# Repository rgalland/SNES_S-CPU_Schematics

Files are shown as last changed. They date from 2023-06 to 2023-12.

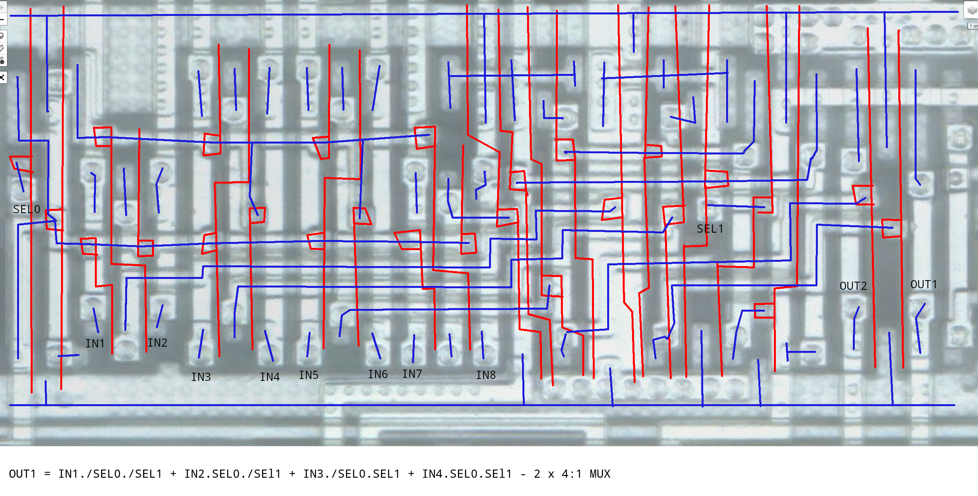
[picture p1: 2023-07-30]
S-CPU_gates/MUX_2x4:1.png

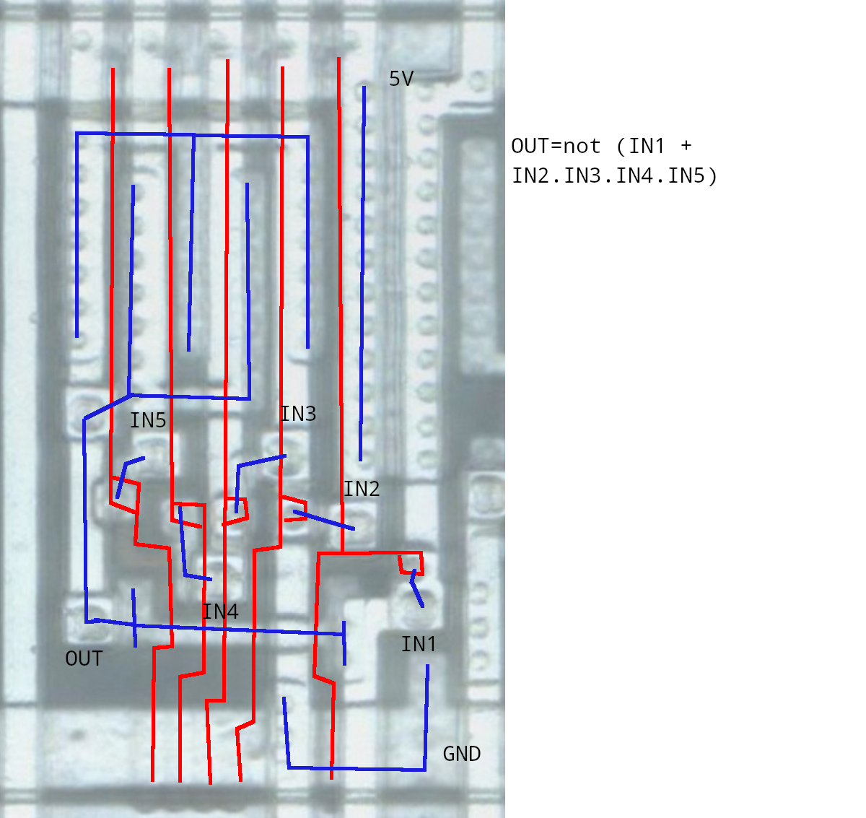
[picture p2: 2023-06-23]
S-CPU_gates/AOI_14.png

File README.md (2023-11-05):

# SNES_S-CPU_Schematics
Reverse engineering of the SNES CPU from die shots found at https://siliconpr0n.org/map/nintendo/s-cpu-a/single/nintendo_s-cpu-a_mcmaster_mz_ns20x.jpg
SVG file has link to die shot but is not included in repository because of its large size. Download it from link above and copy into the root of this repository. 
Inkscape has been used to create and edit the SVG file.

- All cell types have been identified (with the exception of the 65816 section)
- All cells have been allocated a 4 letter unique identifier in the SVG file
- All cells captured are in Kicad schematics
- Schematics rearranged in sections. Only some DMA section still require a few more notes and to be tidied up.
- TODO: Adding 65816 as a component (still some unknow external connections .. to me anyway)

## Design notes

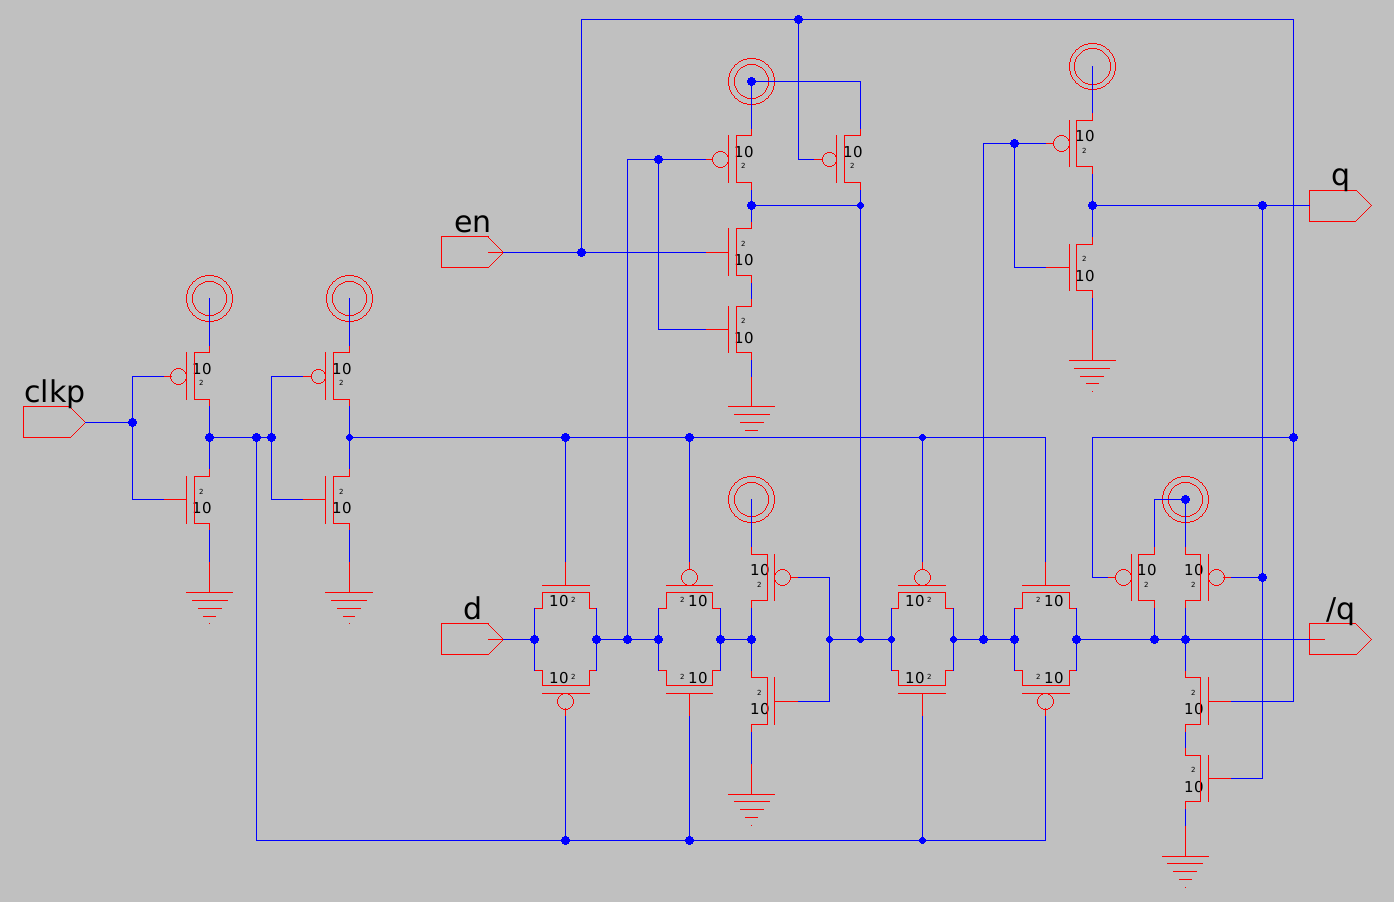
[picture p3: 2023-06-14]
S-CPU_vlsi/dff_wEN_CLKInv.png

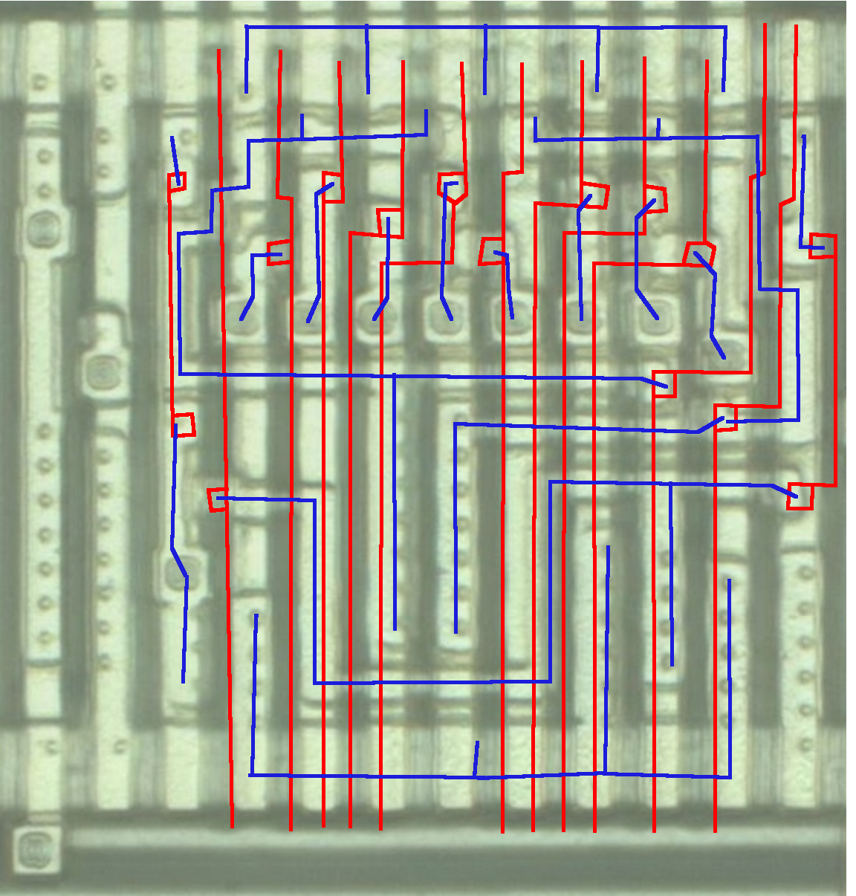
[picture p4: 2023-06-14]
S-CPU_gates/NOR_8.png

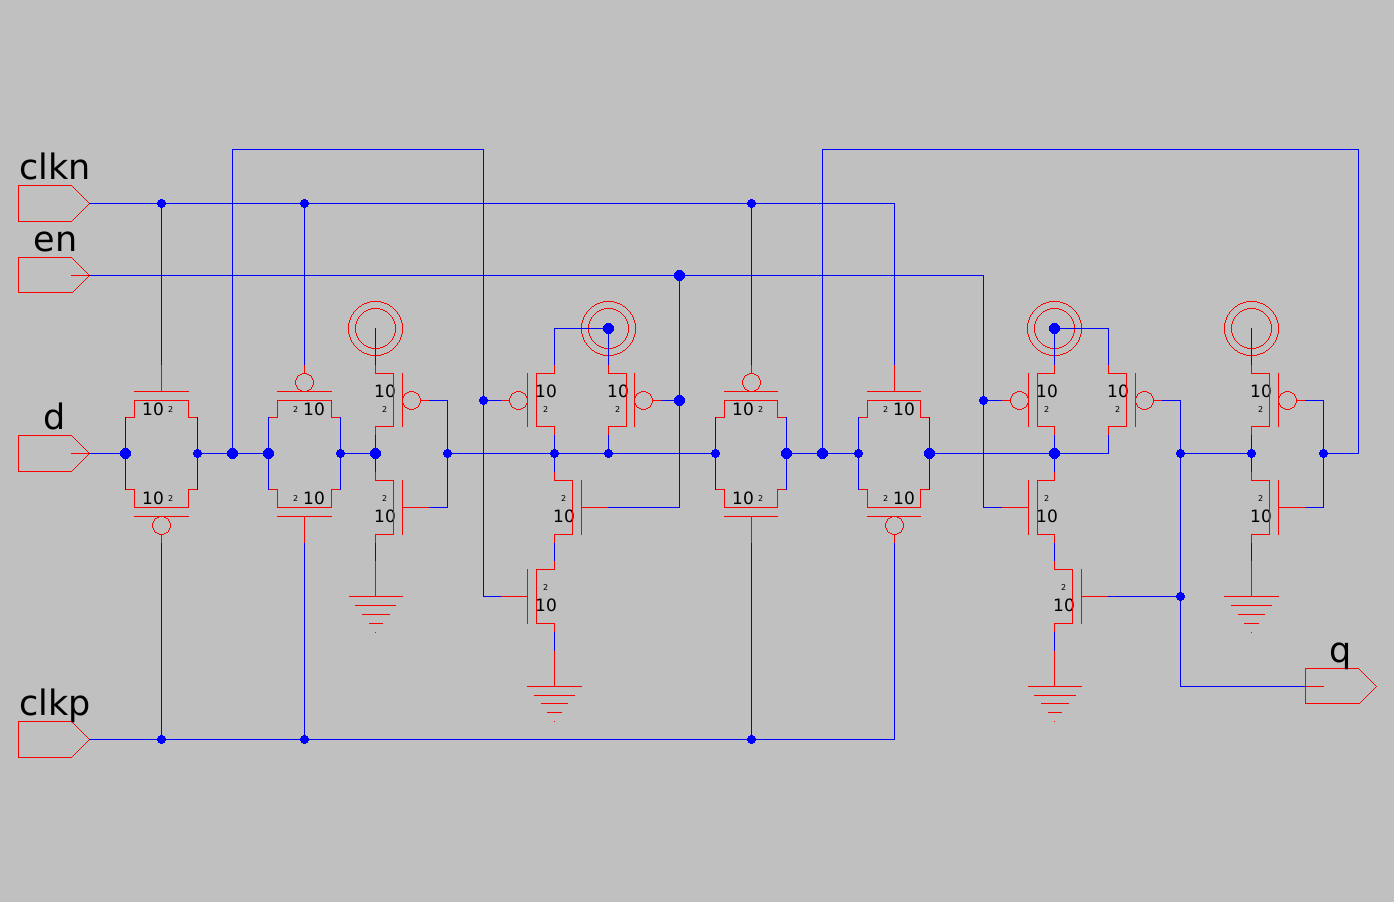
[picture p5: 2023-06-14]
S-CPU_vlsi/dff_wEN_type3.png

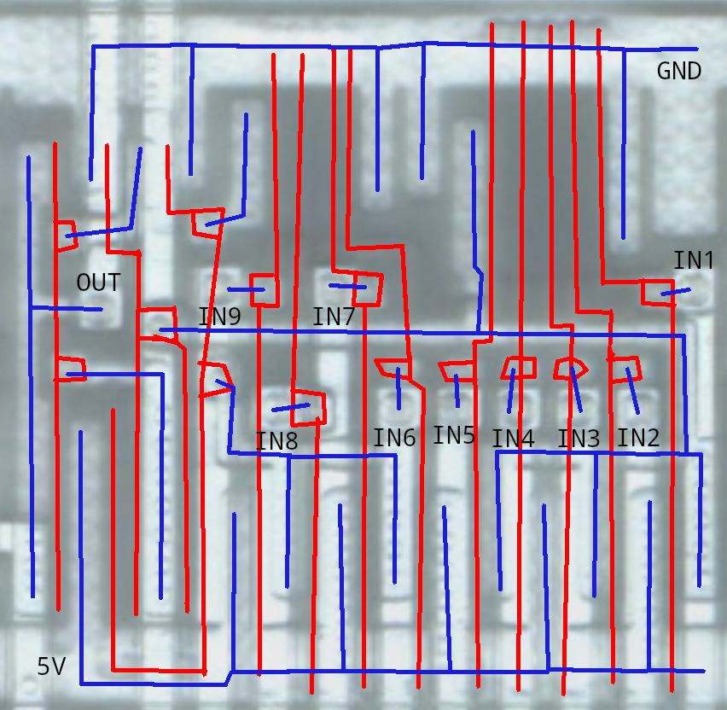
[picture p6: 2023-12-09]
S-CPU_gates/NAND9.png

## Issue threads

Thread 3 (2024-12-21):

Joypad auto-read disable not present in PDF circuit

Fiskbit, 2024-12-21:
Based on some recent tests by undisbeliever, it seems that clearing AUTO_JP_EN during auto-read immediately stops the auto-read process and clears AUTO_JP_READING on all tested CPU revisions. This isn't possible with the auto-read circuit on the "SNES JP REGISTERS" sheet of the S-CPU schematic PDF, which only has AUTO_JP_EN as an input latched on JP_CLK that controls a /RESET signal responsible for starting, not stopping, auto-read. The test result suggests that the VAWR DFFR should actually have a /SET input hooked up to AUTO_JP_EN so that clearing it causes AUTO_JP_READING to immediately become 0, halting the auto-read clock.

Can you verify whether there is a mistake in the circuit here? If VAWR does not actually have a AUTO_JP_EN /SET input, is AUTO_JP_EN connected to some other place in the circuit that might explain this behavior?

rgalland, 2024-12-21:
Nice one. I'll look into it.

Envoyé à partir de Outlook pour Android<https://aka.ms/AAb9ysg>
________________________________
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

rgalland, 2024-12-22:
@Fiskbit , I'm making the edits right now but it is taking a bit longer than expecting since switching to a newer version of Kicad and trying to clear the warnings. It was a mistake on that flip flop you identified that is an SR type flip flop. Please expect the updated version to be ready soon.

Fiskbit, 2024-12-22:
I'm glad to hear it's just this simple difference. Thank you very much for looking into this.

rgalland, 2024-12-24:
@Fiskbit , changes and release done. Using a newer version of kicad has created thousands of warning because of grid size which I have started to go through but there are too of many of them. I'll keep these for the next issue as you are bound to find some more issue.

Closed 2024-12-24.

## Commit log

2023-06-23 Fixed complex gate names. Most fo the cells in the mul div section have been idnetified in SVG file.
    [42XX.kicad_sch, S-CPU.kicad_sch, joypads.kicad_sch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]
2023-06-26 Latch cell identified. Progress in Mul Div section.
    [42XX.kicad_sch, Die_Overlay_Information.ods, S-CPU.kicad_sch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]
2023-06-28 MUL DIV section almost done.
    [42XX.kicad_sch, Die_Overlay_Information.ods, S-CPU.kicad_sch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]
2023-06-29 More MUL DIV section updates,
    [42XX.kicad_sch, S-CPU.kicad_sch, addrdatabuses.kicad_sch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]
2023-06-30 D latch with reset and tri state output identified
    [42XX.kicad_sch, Die_Overlay_Information.ods, S-CPU.kicad_sch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]
2023-07-02 ADDR and DAT bus progress
    [42XX.kicad_sch, Die_Overlay_Information.ods, S-CPU.kicad_sch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]
2023-07-10 DMA progress. Most gates identified.
    [42XX.kicad_sch, S-CPU.kicad_sch, addrdatabuses.kicad_sch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]
2023-07-19 Some cells had the wrong ID in the producter remainder sheet. Allocation of new names in spreadsheet for cells in the DMA section
    [42XX.kicad_sch, Die_Overlay_Information.ods, S-CPU.kicad_sch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]
2023-07-30 Bit DMA section update. Untangled a lot of singals. DMA addressing decoding worked out + connections to DMA RAM.
    [42XX.kicad_sch, Die_Overlay_Information.ods, S-CPU.kicad_sch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]
2023-08-08 NOR SR latch identified.
    [42XX.kicad_sch, Die_Overlay_Information.ods, S-CPU.kicad_sch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]
2023-09-06 DMA logic update + some mistakes found in gate identification. Found while working out the DMA priority encoder.
    [42XX.kicad_sch, Die_Overlay_Information.ods, S-CPU.kicad_sch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]
2023-09-18 Further updates in the DMA region. SYS clock identified at last!
    [42XX.kicad_sch, DMAothers.kicad_sch, Die_Overlay_Information.ods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]
2023-09-20 More updates in DMA section.
    [42XX.kicad_sch, DMAothers.kicad_sch, S-CPU.kicad_sch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]
2023-09-26 Fixed reset signal in DMA section.
    [42XX.kicad_sch, DMAothers.kicad_sch, S-CPU.kicad_sch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]
2023-09-29 Another latch with reset identified. TCKSEL demux cell worked out + notes added to schematics.
    [42XX.kicad_sch, DMAothers.kicad_sch, Die_Overlay_Information.ods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]
2023-10-11 Almost all cells captured in schematicAlmost all cells captured in schematics. Enter the commit message for your changes. Lines starting
    [42XX.kicad_sch, DMAothers.kicad_sch, Die_Overlay_Information.ods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]
2023-10-13 Progress in DMA section. Fixed some DFF output issues.
    [42XX.kicad_sch, DMAothers.kicad_sch, Die_Overlay_Information.ods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]
2023-10-17 Update in DMA sections - most debug signals identified. Error found in SYS clk generation. Simulation show correct 6, 8 and 12 cycle SYSCLK modes.
    [42XX.kicad_sch, DMAothers.kicad_sch, Die_Overlay_Information.ods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]
2023-10-18 Schematics update.
    [42XX.kicad_sch, DMAothers.kicad_sch, S-CPU.kicad_sch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]
2023-10-19 Schematics tidying in progress.
    [42XX.kicad_sch, DMAothers.kicad_sch, S-CPU.kicad_sch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]
2023-10-21 Big update on the hierarchical sheet. DMA section update too.
    [42XX.kicad_sch, DMAothers.kicad_sch, S-CPU.kicad_sch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]
2023-10-22 DMA section update. Fixed gate related to INC/DEC and BORROW/CARRY FLAG
    [42XX.kicad_sch, DMAothers.kicad_sch, Die_Overlay_Information.ods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]
2023-10-25 DMA section update. Found errors between some MUX and MUXI gates.
    [42XX.kicad_sch, DMAothers.kicad_sch, Die_Overlay_Information.ods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]
2023-10-27 Found issue in the HDMA section. No seems to make sense. HDMA has 2 ways to start depending on whether GDMA is currently running.
    [42XX.kicad_sch, DMAothers.kicad_sch, addrdatabuses.kicad_sch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]
2023-10-27 Further tidying of the DMA section. New sheet added dedicated to GDMA/ HDMA Start and Stop signals.
    [42XX.kicad_sch, DMAothers.kicad_sch, addrdatabuses.kicad_sch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]
2023-10-30 General update a
    [42XX.kicad_sch, DMAothers.kicad_sch, addrdatabuses.kicad_sch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]
2023-11-01 HDMA section seems correct after all. More notes added.
    [42XX.kicad_sch, DMAothers.kicad_sch, addrdatabuses.kicad_sch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]
2023-11-03 More DMA updates - extra notes regarding behaviour
    [42XX.kicad_sch, DMAothers.kicad_sch, addrdatabuses.kicad_sch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]
2023-11-05 Identified some DFFs as being DFFs with SET input rather than RESET input. It helps explaining a lot of beahiour in the MUL/DIV section and in the DMA section.
    [42XX.kicad_sch, DMAothers.kicad_sch, addrdatabuses.kicad_sch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]
2023-12-09 Fix ERC errors in schematics.
    [42XX.kicad_sch, 65c816.kicad_sch, DMAothers.kicad_sch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]
2023-12-11 More notes added to detail HDMA steps
    [DMAothers.kicad_sch, S-CPU.kicad_sch, dma.kicad_sch]
2024-02-12 Big rework on the hierachical sheet to make thigs a bit clearer. PDF exported for Rev 0.1.
    [42XX.kicad_sch, 65c816.kicad_sch, DMAothers.kicad_sch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]
2024-12-24 Fixed VAWR which should have been an SR DFF (to fix issue #3 raised in github)
    [42XX.kicad_sch, 65c816.kicad_sch, DMAothers.kicad_sch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]
